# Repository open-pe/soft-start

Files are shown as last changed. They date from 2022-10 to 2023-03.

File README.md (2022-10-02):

Simple soft start circuit with power MOSFET and NTC.
It is designed to limit in-rush current of a DCDC converter connected to a battery with XT90i (like XT90 + 2 signal pins) connectors. 
The additional signal pin makes sure that the circuit resets after the connector is unplugged. Otherwise, it can be powered by the input capacitor of the load and doesn't "know" that the battery power is lost.
Because battery voltage changes with battery SoC, absolute voltage at load input cannot tell wether the input capacitance is fully charged.

The 78L15 is the power supply for MOSFET driving and is a reference voltage at the same time. Q2 protects the NTC from long current exposure if the connector is plugged in to slowly or not properly.
The comparator switches on once the voltage drop accross the NTC falls below the value defined by the potentiometer and R1,R2. With the given resistor values, the circuit works with battery voltage upto 60V.
Note that 78L15 max input is 30V.

You can omit and short Q2 if you dont use a seperate power supply for circuit.

NTCs
https://datasheetspdf.com/pdf/814993/EXSENSE/NTC-10D7/1

MOSFETS

* IPP024N08NF2SAKMA1 (80V, 2.4mohm, Id100 139A)
* IRF100B201 (100V, 4.2mohm, Id100 136A)

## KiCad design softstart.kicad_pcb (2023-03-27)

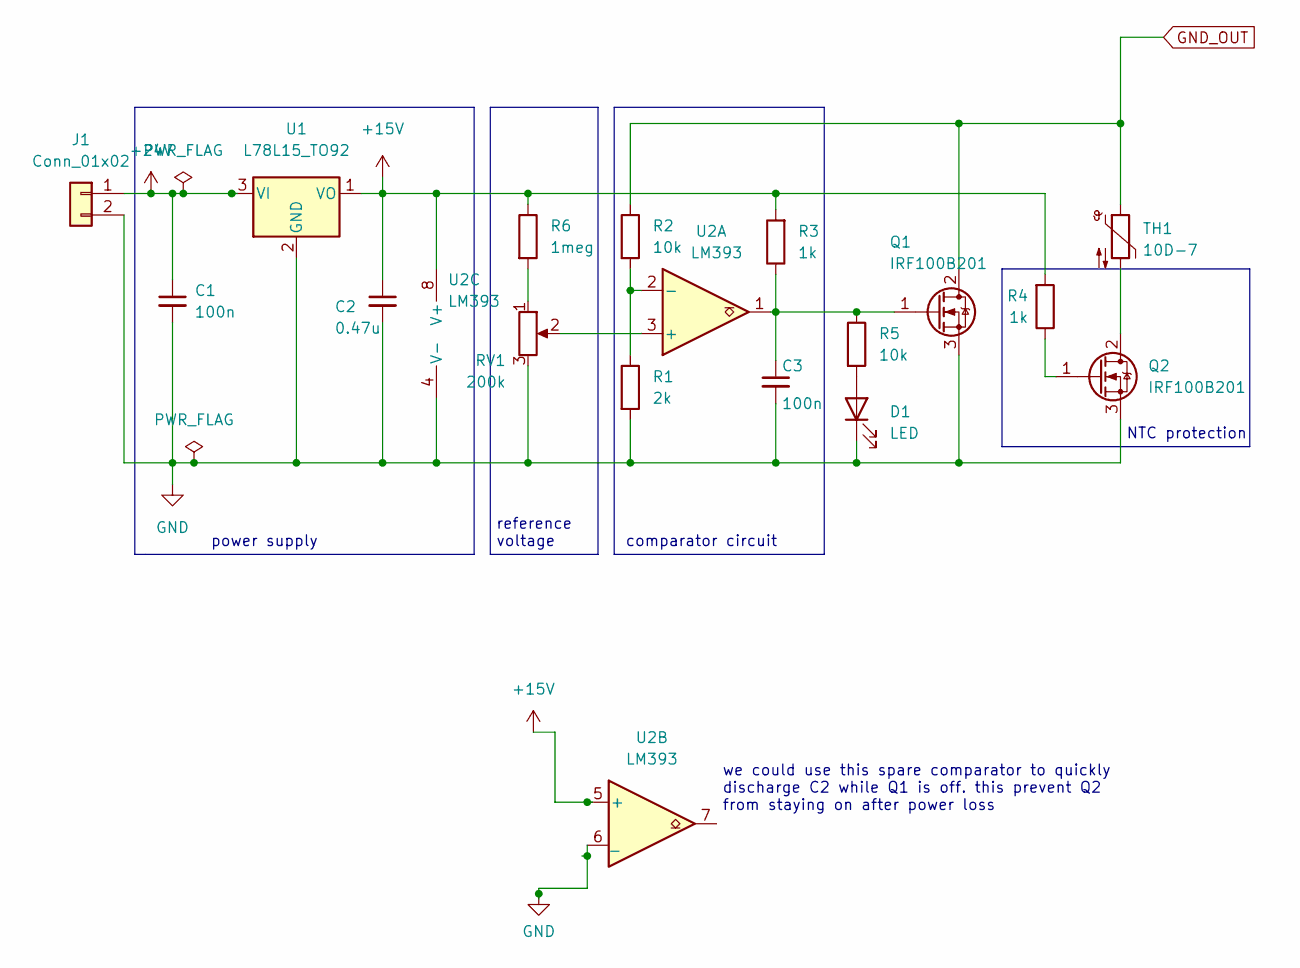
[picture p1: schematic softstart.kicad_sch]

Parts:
C1, C3: 100n; C_0603_1608Metric_Pad1.08x0.95mm_HandSolder
C2: 0.47u; C_0805_2012Metric_Pad1.18x1.45mm_HandSolder
D1: LED; LED_D5.0mm
J1: Conn_01x02; PinHeader_1x02_P2.54mm_Vertical
Q1: IRF100B201; TO-220-3_Horizontal_TabDown
Q2: IRF100B201; TO-220-3_Vertical
R1: 2k; R_0805_2012Metric_Pad1.20x1.40mm_HandSolder
R2, R5: 10k; R_0805_2012Metric_Pad1.20x1.40mm_HandSolder
R3, R4: 1k; R_0805_2012Metric_Pad1.20x1.40mm_HandSolder
R6: 1meg; R_0805_2012Metric_Pad1.20x1.40mm_HandSolder
RV1: 200k; Potentiometer_Bourns_3296W_Vertical
TH1: 10D-7; R_Axial_DIN0207_L6.3mm_D2.5mm_P7.62mm_Horizontal
U1: L78L15_TO92; TO-92_Inline
U2: LM393; DIP-8_W7.62mm

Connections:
+15V: C2.1, R3.2, R4.2, R6.1, U1.1 (VO), U2.5 (+), U2.8 (V+)
+24V: C1.1, J1.1, U1.3 (VI)
GND: C1.2, C2.2, C3.2, D1.1 (K), J1.2, Q1.3 (S), Q2.3 (S), R1.2, RV1.3, U1.2 (GND), U2.4 (V-), U2.6 (_)
GND_OUT: Q1.2 (D), R2.1, TH1.1
unnamed: D1.2 (A), R5.2
unnamed: C3.1, Q1.1 (G), R3.1, R5.1, U2.1
unnamed: Q2.1 (G), R4.1
unnamed: Q2.2 (D), TH1.2
unnamed: R1.1, R2.2, U2.2 (-)
unnamed: R6.2, RV1.1
unnamed: RV1.2, U2.3 (+)

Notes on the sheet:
NTC protection
we could use this spare comparator to quickly discharge C2 while Q1 is off. this prevent Q2 from staying on after power loss
power supply
reference voltage
comparator circuit

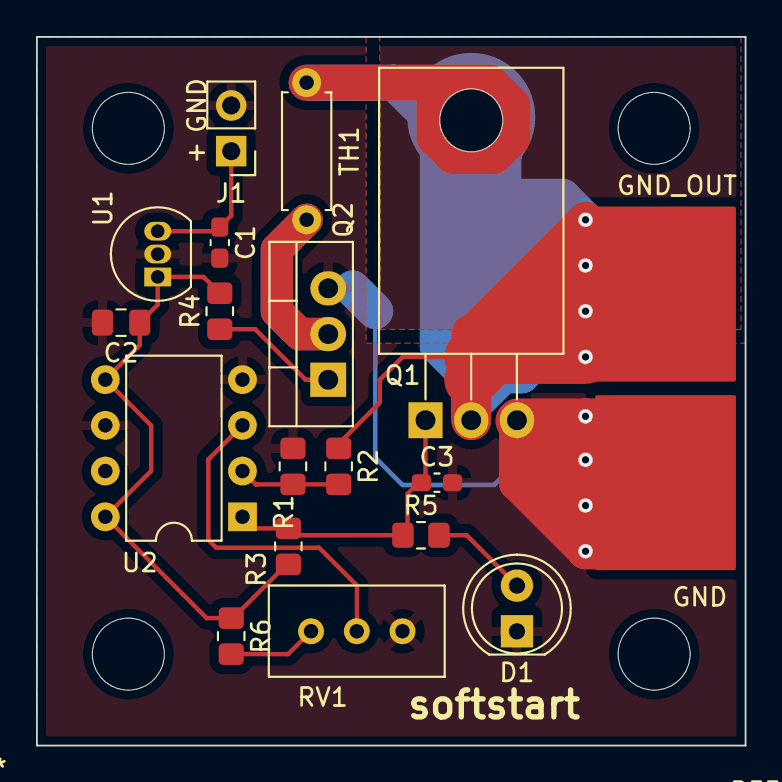
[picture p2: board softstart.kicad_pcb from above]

Board: 2 copper layers, 39.4 x 39.4 mm, 17 parts (0 on the bottom side), 11 nets.

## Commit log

2022-10-02 add kicad project
    [softstart.kicad_pcb, softstart.kicad_sch]
2023-03-27 fix comp output
    [softstart.kicad_pcb, softstart.kicad_sch]
